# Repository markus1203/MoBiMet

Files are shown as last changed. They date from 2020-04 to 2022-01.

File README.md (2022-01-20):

# MoBiMet
Development of a Mobile Biometeorology Sensor (INTERREG V, "Clim'Ability Design")



MoBiMet_Sketch_20210421

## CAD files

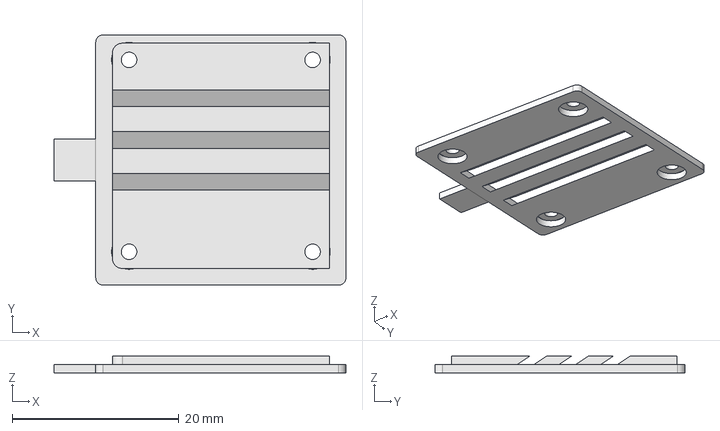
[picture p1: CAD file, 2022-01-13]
Python_Scripts_and_3D_Model/3D_Model/D_klein_0922.FCStd
35.0 x 30.0 x 2.00 mm

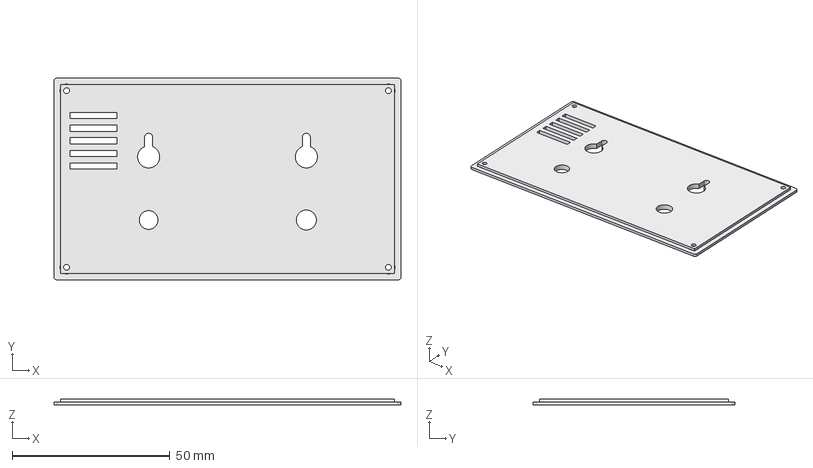
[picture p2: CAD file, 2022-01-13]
Python_Scripts_and_3D_Model/3D_Model/D_09_17.FCStd
110.0 x 64.0 x 2.00 mm

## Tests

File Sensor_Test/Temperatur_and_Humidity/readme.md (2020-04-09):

# Temperature & Humidity Sensor Test

Comparison between the sensors AM2320,DHT22,HTU21D,MCP9808,BME680, BME280 and the CS215 in the climate station at Werthmannstrasse 10 from 3rd to 6th of March, 2020.

 

Temperature
============

Table 1: Coefficients to correct temperatures and root mean square error (RMSE) of the raw and calibrated temperatures relative to the climate station in K

|Sensor | a0 (Offset) | a1 (Slope) | RMSE (raw) | RMSE (calib) |
| --- | ---: | ---: |  ---: | ---: |
|AM2320	|-0.4452 |	1.02780	|0.2107049|	0.079546|
|1_DHT22	|-0.2868|	1.02920	|0.1750821	|0.089617
|2_DHT22	|-0.3820|	1.03000	|0.1847389	|0.094950
|1_HTU21D	|0.1769	|1.00440	|0.2388976	|0.078499
|2_HTU21D	|0.4499	|1.00280	|0.4875104	|0.086191
|1_MCP9808|	-0.2153	|1.01150|	0.1523272	|0.109667
|2_MCP9808|	0.0167|	1.00716	|0.1587282	|0.121885
|1_BME680	|0.0541	|0.99297	|0.08693147	|0.075257
|2_BME680	|-0.0829|	0.98992|	0.2188592	|0.082456
|1_BME280	|0.9421	|0.99980|	0.9483656	|0.124448
|2_BME280	|0.7338	|1.00180|	0.7602216	|0.110038

Humidity
============

Table 2: Coefficients to correct vapor pressure and root mean square error (RMSE) of the raw and calibrated vapor pressure relative to the climate station in hPa

|Sensor | a0 (Offset) | a1 (Slope) | RMSE (raw) | RMSE (calib) |
| --- | ---: | ---: |  ---: | ---: |
|AM2320	|0.8477	|0.74930	|1.189864	|0.231711|
|1_DHT22	|0.6247	|0.94360|	0.2714386	|0.087445|
|2_DHT22	|0.6745	|0.89050|	0.1458398	|0.094100|
|1_HTU21D	|0.3980	|0.95980|	0.1908347	|0.138263|
|2_HTU21D	|0.4823	|0.95580|	0.232505	|0.131855|
|1_BME680	|1.5380	|0.79600|	0.2779574	|0.136056|
|2_BME680	|1.5892	|0.79630|	0.3271391	|0.139714|
|1_BME280 |-0.0493|	1.16144|	0.9195801|	0.134975|

Pressure
============

Table 3: Coefficients to correct  pressure and root mean square error (RMSE) of the raw and calibrated pressure relative to the climate station in hPa

|Sensor | a0 (Offset) | a1 (Slope) | RMSE (raw) | RMSE (calib) |
| --- | ---: | ---: |  ---: | ---: |
|1_BME680|	53.7062|	0.9431|	2.582043|	0.08572349|
|2_BME680|	90.7679|	0.9042|	4.176867|	0.1304444|
|1_BME280| 56.7623|	0.9403|	2.320534|	0.09050464|
|2_BME280|	54.7224|	0.9419|	2.794057|	0.08769271|

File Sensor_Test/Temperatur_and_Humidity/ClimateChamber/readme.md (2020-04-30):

Temperature
============

Table 1: Coefficients to correct temperatures and root mean square error (RMSE) of the raw and calibrated temperatures relative to the FLUKE1502 Thermometer in K in the Climate Chamber

|sensors|	offset|	slope|	rmse_raw	|rmse_calib|
| --- | ---: | ---: |  ---: | ---: |
|AM2320|	-0.223520657	|1.018391454	|0.276085797	|0.054778603|
|DHT22_1	|-0.153542897	|1.021439063|	0.410822958	|0.071755907|
|DHT22_2	|-0.250318367	|1.021306246	|0.325797709	|0.06806436|
|HTU21D_1|	0.179203118	|1.002364234	|0.245580942	|0.062729972|
|HTU21D_2	|0.464937897	|1.0023549	|0.526442766	|0.069617966|
|MCP9808_1	|-0.093615792	|1.004846833|	0.092353552|	0.079032812|
|MCP9808_2	|0.021288028	|1.003977209	|0.15907906	|0.100786365|
|BME680_1	|0.055285168	|0.988881444	|0.245291751	|0.05237806|
|BME680_2	|0.033774245	|0.985185244	|0.36281283	|0.058537775|
|BME280_1	|0.964163465	|0.995887152	|0.873013617	|0.098679036|
|BME280_2	|0.892429899	|0.992954993	|0.729877614|	0.065070383|

Only the red parts were used for the calibration:
Fluke_subset

Sensors vs Time

Sensors_vs_Time

Sensors vs Fluke

Korrelation

Sensors in the Climate Chamber:



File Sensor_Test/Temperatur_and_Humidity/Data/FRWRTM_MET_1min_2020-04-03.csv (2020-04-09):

TOA5 | FRWRTM | CR1000X | 2600 | CR1000X.Std.03.02 | CPU:FRWRTM007.CR1X | 29908 | MET_1min
TIMESTAMP | RECORD | MET_PTB100_PressureSeaLevel_hPa_Avg | MET_PTB100_PressureActual_hPa_Avg | MET_CS215_AirTemperature_degC_Avg | MET_CS215_RelHumidity_percent_Avg | MET_CS215_DewPoint_degC_Avg | MET_CS215_VapourPressure_hPa_Avg | MET_CS215_VapPressDeficit_hPa_Avg | MET_CS215_MixingRatio_gKg_Avg | MET_CS107_SoilT05cm_degC_Avg | MET_CS107_SoilT20cm_degC_Avg
TS | RN | hPa | hPa | degC | % | degC | hPa | hPa | g/kg | degC | degC
 |  | Avg | Avg | Avg | Avg | Avg | Avg | Avg | Avg | Avg | Avg
2020-04-03 00:01:00 | 61074 | 1013.366 | 980.7032 | 4.41625 | 63.1435 | -1.998489 | 5.280471 | 3.08218 | 3.367561 | 9.704125 | 9.039716
2020-04-03 00:02:00 | 61075 | 1013.399 | 980.7369 | 4.414667 | 63.11491 | -2.006162 | 5.277497 | 3.084231 | 3.365538 | 9.698626 | 9.038014
2020-04-03 00:03:00 | 61076 | 1013.391 | 980.729 | 4.40175 | 63.35625 | -1.966413 | 5.292907 | 3.061297 | 3.375446 | 9.693006 | 9.036618
2020-04-03 00:04:00 | 61077 | 1013.391 | 980.7281 | 4.392 | 63.61483 | -1.920085 | 5.310905 | 3.037627 | 3.386989 | 9.689974 | 9.03519
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

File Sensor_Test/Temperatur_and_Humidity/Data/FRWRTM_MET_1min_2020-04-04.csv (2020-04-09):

TOA5 | FRWRTM | CR1000X | 2600 | CR1000X.Std.03.02 | CPU:FRWRTM007.CR1X | 29908 | MET_1min
TIMESTAMP | RECORD | MET_PTB100_PressureSeaLevel_hPa_Avg | MET_PTB100_PressureActual_hPa_Avg | MET_CS215_AirTemperature_degC_Avg | MET_CS215_RelHumidity_percent_Avg | MET_CS215_DewPoint_degC_Avg | MET_CS215_VapourPressure_hPa_Avg | MET_CS215_VapPressDeficit_hPa_Avg | MET_CS215_MixingRatio_gKg_Avg | MET_CS107_SoilT05cm_degC_Avg | MET_CS107_SoilT20cm_degC_Avg
TS | RN | hPa | hPa | degC | % | degC | hPa | hPa | g/kg | degC | degC
 |  | Avg | Avg | Avg | Avg | Avg | Avg | Avg | Avg | Avg | Avg
2020-04-04 00:01:00 | 62514 | 1019.54 | 986.8771 | 4.966833 | 70.81525 | 0.1023204 | 6.153114 | 2.535854 | 3.902868 | 10.15777 | 9.382245
2020-04-04 00:02:00 | 62515 | 1019.51 | 986.8472 | 4.961 | 70.84783 | 0.1030833 | 6.153452 | 2.531997 | 3.903202 | 10.15398 | 9.380699
2020-04-04 00:03:00 | 62516 | 1019.554 | 986.8918 | 4.959416 | 70.79058 | 0.09037272 | 6.147804 | 2.53669 | 3.89942 | 10.15125 | 9.378841
2020-04-04 00:04:00 | 62517 | 1019.524 | 986.8618 | 4.943333 | 70.80316 | 0.07738495 | 6.142044 | 2.532771 | 3.895864 | 10.1467 | 9.377414
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

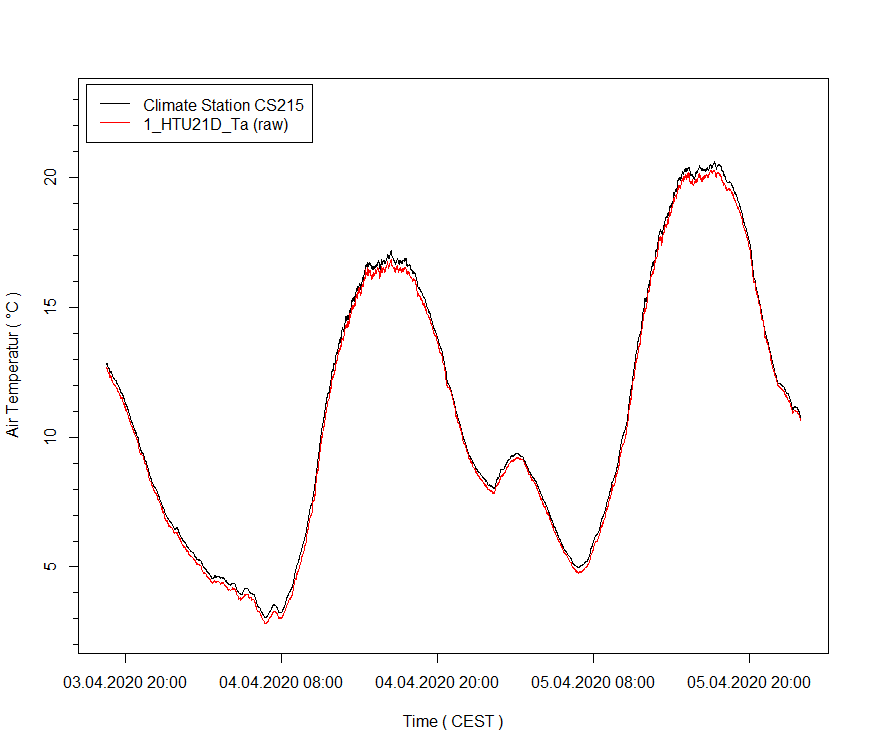
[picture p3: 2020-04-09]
Sensor_Test/Temperatur_and_Humidity/Ta/1_HTU21DvsTIME.png

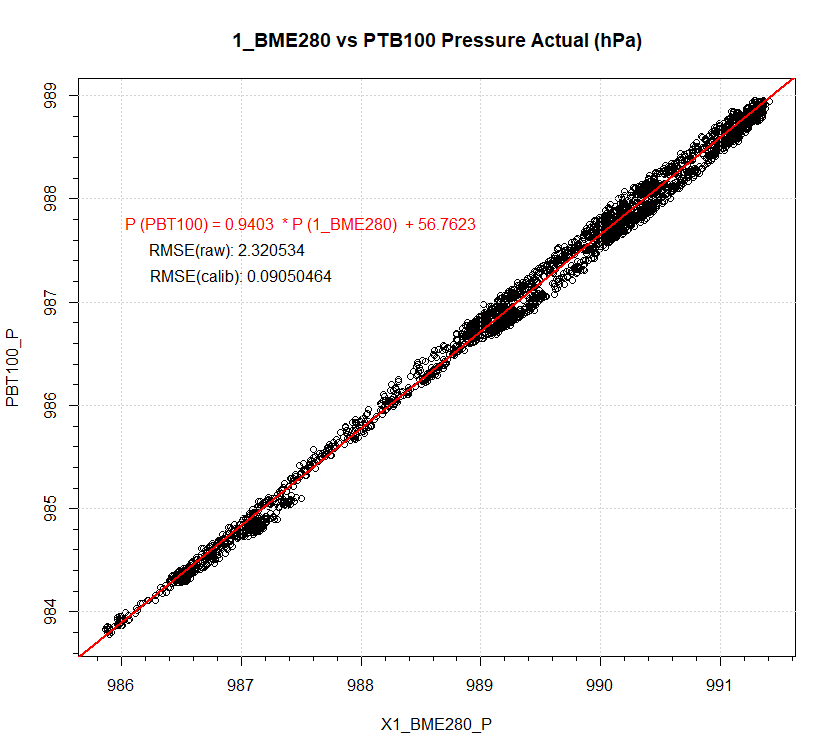
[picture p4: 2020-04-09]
Sensor_Test/Temperatur_and_Humidity/Pressure/1_BME280_PvsPBT100.png

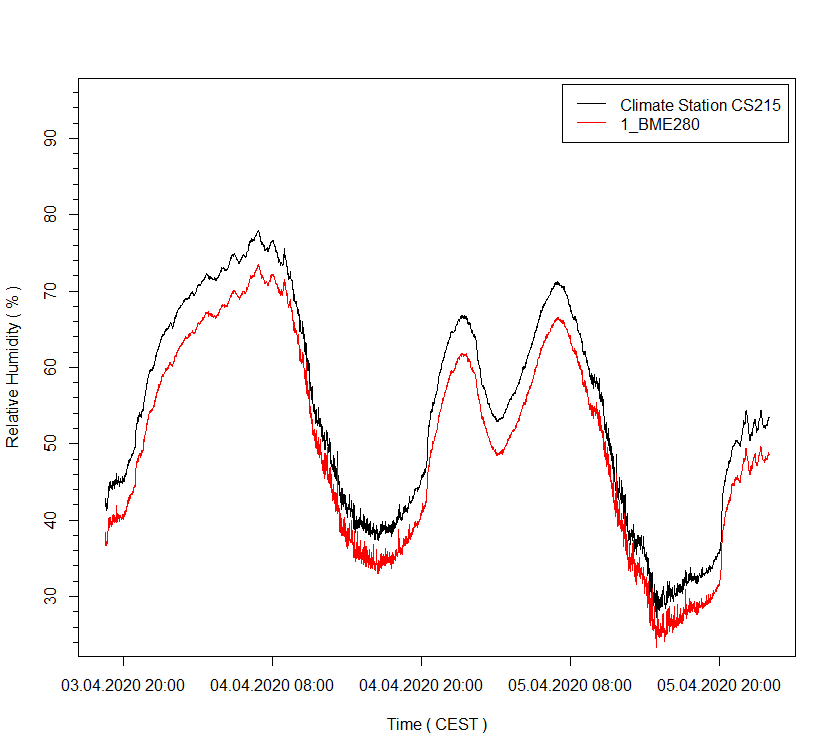
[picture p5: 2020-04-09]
Sensor_Test/Temperatur_and_Humidity/Humidity/1_BME280_RHvsTIME.png

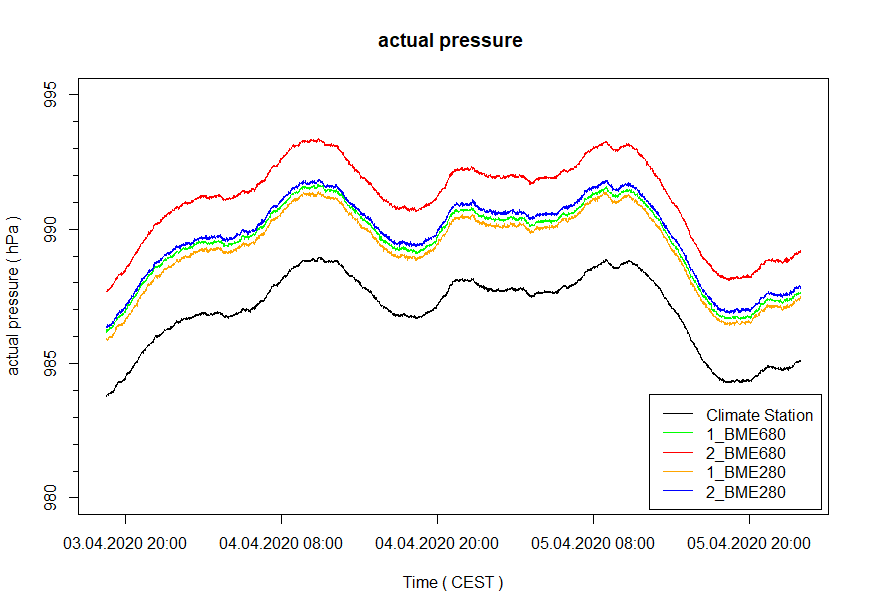
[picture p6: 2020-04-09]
Sensor_Test/Temperatur_and_Humidity/Pressure/P_all.png

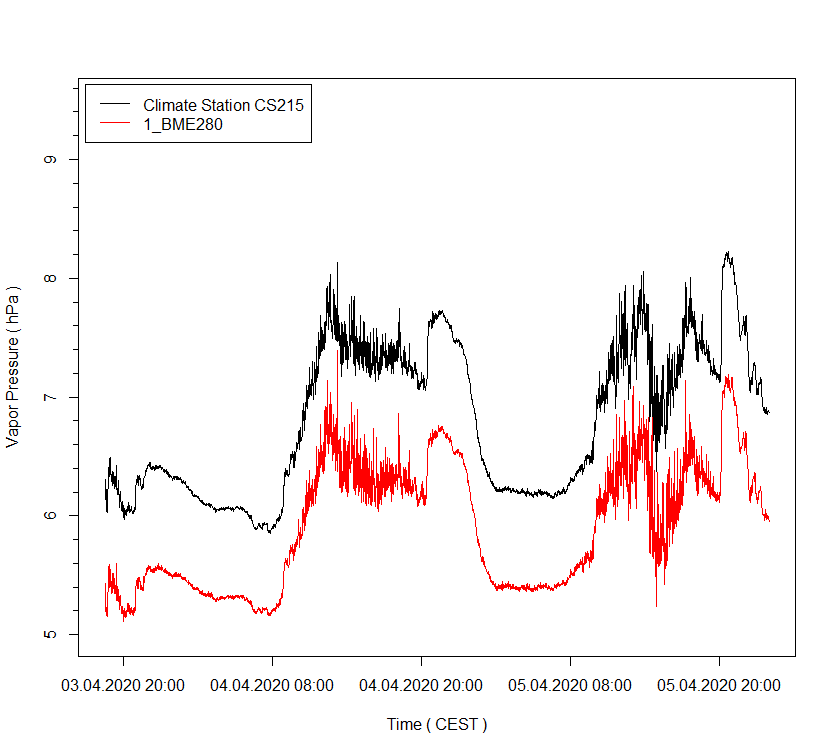
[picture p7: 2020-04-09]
Sensor_Test/Temperatur_and_Humidity/Humidity/1_BME280_VPvsTime.png

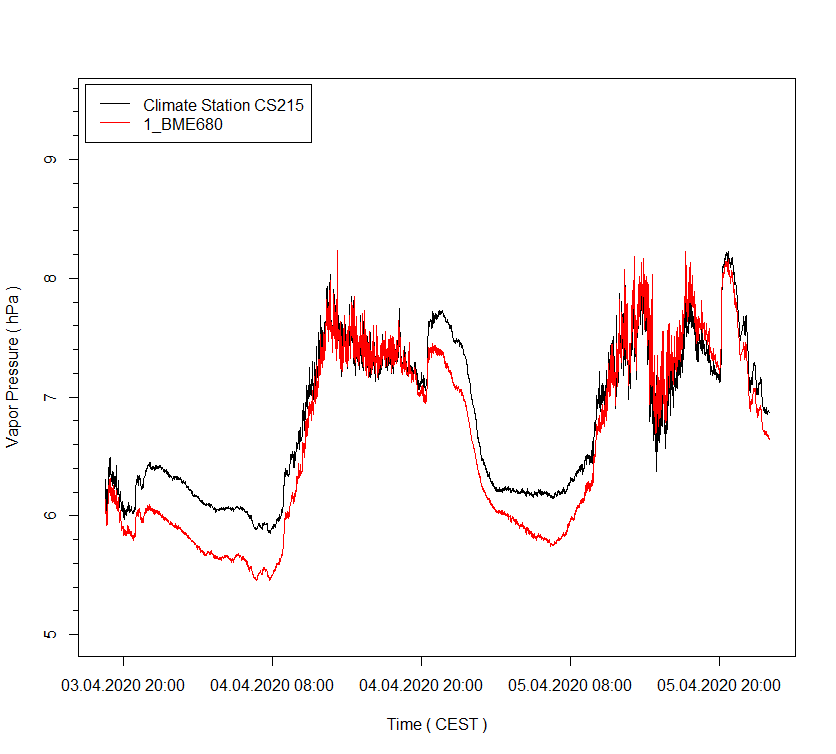
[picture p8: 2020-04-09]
Sensor_Test/Temperatur_and_Humidity/Humidity/1_BME680_VPvsTIME.png

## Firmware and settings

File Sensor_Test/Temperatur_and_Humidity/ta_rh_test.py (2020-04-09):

#! /usr/bin/python
# -*- coding: utf-8 -*-

from __future__ import print_function
import math
import socket
import posix
from fcntl import ioctl
import Adafruit_DHT
import smbus
import Adafruit_MCP9808.MCP9808 as MCP9808
import os, sys, time, signal
import htu21d.htu21d as htu
import bme680



Zeit=time.strftime("%Y-%m-%d %H:%M:%S") 

# DHT22

dht22_pin1 = 4 # pin for DHT22 Data
dht22_sensor1 = Adafruit_DHT.DHT22

dht22_humidity1, dht22_temperature1 = Adafruit_DHT.read_retry(dht22_sensor1, dht22_pin1)

dht22_pin2 = 17 # pin for DHT22 Data
dht22_sensor2 = Adafruit_DHT.DHT22

dht22_humidity2, dht22_temperature2 = Adafruit_DHT.read_retry(dht22_sensor2, dht22_pin2)

#AM2320

class AM2320:
  I2C_ADDR = 0x5c
  I2C_SLAVE = 0x0703 

  def __init__(self, i2cbus = 1):
    self._i2cbus = i2cbus

  @staticmethod
  def _calc_crc16(data):
    crc = 0xFFFF
    for x in data:
      crc = crc ^ x
      for bit in range(0, 8):
        if (crc & 0x0001) == 0x0001:
          crc >>= 1
          crc ^= 0xA001
        else:
          crc >>= 1
    return crc

  @staticmethod
  def _combine_bytes(msb, lsb):
    return msb << 8 | lsb


  def readSensor(self):
    fd = posix.open("/dev/i2c-%d" % self._i2cbus, posix.O_RDWR)

    ioctl(fd, self.I2C_SLAVE, self.I2C_ADDR)
  
    # wake AM2320 up, goes to sleep to not warm up and affect the humidity sensor 
    # This write will fail as AM2320 won't ACK this write
    try:
      posix.write(fd, b'\0x00')
    except:
      pass
    time.sleep(0.001)  #Wait at least 0.8ms, at most 3ms
  
    # write at addr 0x03, start reg = 0x00, num regs = 0x04 */  
    posix.write(fd, b'\x03\x00\x04')
    time.sleep(0.0016) #Wait at least 1.5ms for result

    data = bytearray(posix.read(fd, 8))
  
    # Check data[0] and data[1]
    if data[0] != 0x03 or data[1] != 0x04:
      raise Exception("First two read bytes are a mismatch")

    # CRC check
    if self._calc_crc16(data[0:6]) != self._combine_bytes(data[7], data[6]):
      raise Exception("CRC failed")
    

    temp = self._combine_bytes(data[4], data[5])
    if temp & 0x8000:
      temp = -(temp & 0x7FFF)
    temp /= 10.0
  
    humi = self._combine_bytes(data[2], data[3]) / 10.0

    return (temp, humi)  

am2320 = AM2320(1)
(am2320t,am2320h) = am2320.readSensor()
#print("{0:.1f} %".format(am2320h),"{0:.1f} C".format(am2320t))

#HUT21D-F
sensor = htu.HTU21D()
htu_ta=sensor.read_temperature()
htu_rh=sensor.read_humidity()
sensor.dewpoint()
sensor.reset()

sensor2 = htu.HTU21D(4)
htu_2_ta=sensor2.read_temperature()
htu_2_rh=sensor2.read_humidity()
sensor2.dewpoint()
sensor2.reset()

#MCP9808
sensor_mcp1 = MCP9808.MCP9808()
mcp_1_ta = sensor_mcp1.readTempC()

sensor_mcp2 = MCP9808.MCP9808(address=0x18, busnum=4)
mcp_2_ta = sensor_mcp2.readTempC()


# BME680

sensor_bme680_1 = bme680.BME680(0x77)

sensor_bme680_1.set_humidity_oversample(bme680.OS_2X)
sensor_bme680_1.set_pressure_oversample(bme680.OS_4X)
sensor_bme680_1.set_temperature_oversample(bme680.OS_8X)
sensor_bme680_1.set_filter(bme680.FILTER_SIZE_3)

sensor_bme680_1.set_gas_status(bme680.ENABLE_GAS_MEAS)
sensor_bme680_1.set_gas_heater_temperature(320)
sensor_bme680_1.set_gas_heater_duration(150)
sensor_bme680_1.select_gas_heater_profile(0)

sensor_bme680_2 = bme680.BME680(0x76)

sensor_bme680_2.set_humidity_oversample(bme680.OS_2X)
sensor_bme680_2.set_pressure_oversample(bme680.OS_4X)
sensor_bme680_2.set_temperature_oversample(bme680.OS_8X)
sensor_bme680_2.set_filter(bme680.FILTER_SIZE_3)

sensor_bme680_2.set_gas_status(bme680.ENABLE_GAS_MEAS)
sensor_bme680_2.set_gas_heater_temperature(320)
sensor_bme680_2.set_gas_heater_duration(150)
sensor_bme680_2.select_gas_heater_profile(0)

# BME280

import bme280_b3
bme280_1_ta,bme280_1_p,bme280_1_rh = bme280_b3.readBME280All()
import bme280_b4
bme280_2_ta,bme280_2_p,bme280_2_rh = bme280_b4.readBME280All()



print ("Time: "+ str(Zeit)+"\n"+ "AM2320 Ta: " + str(round(am2320t,5)) + " AM2320 RH: " + str(round(am2320h,5)) +"\n"+"DHT22_1 Ta: " + str(round(dht22_temperature1,5)) + " DHT22_1 RH: " + str(round(dht22_humidity1,5)) + " // " + " DHT22_2 Ta: " + str(round(dht22_temperature2,5)) + " DHT22_2 RH: " + str(round(dht22_humidity2,5))+ "\n"+"HTU21D_1 Ta: " +str(round(htu_ta,3)) +" HTU21D_1 RH: "+str(round(htu_rh,3)) +" // "+ " HTU21D_2 Ta: " +str(round(htu_2_ta,3)) +" HTU21D_2 RH: " +str(round(htu_2_rh,3)) + "\n"+"MCP9808_1 Ta: " + str(round(mcp_1_ta,3))+" MCP9808_2 Ta: " + str(round(mcp_2_ta,3))+ "\n"+"BME280_1_Ta : "+str(round(bme280_1_ta,3))+" BME280_1_RH : "+str(round(bme280_1_rh,3))+" // "+" BME280_2_Ta : "+str(round(bme280_2_ta,3))+" BME280_2_RH : "+str(round(bme280_2_rh,3))+ "\n"+ "BME680_1 Ta: "+str(round(sensor_bme680_1.data.temperature,3))+" BME680_1 RH: "+str(round(sensor_bme680_1.data.humidity,3)) + " // " + " BME680_2 Ta: "+str(round(sensor_bme680_2.data.temperature,3))+" BME680_2 RH: "+str(round(sensor_bme680_2.data.humidity,3)))

logfile_path = "/home/pi/Desktop/"
logfile = logfile_path+"Ta_RH_Test-"+time.strftime("%Y-%m-%d")+".csv"
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
